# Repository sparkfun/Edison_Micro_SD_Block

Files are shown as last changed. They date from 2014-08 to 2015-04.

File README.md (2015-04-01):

SparkFun Edison microSD Block
============================

SparkFun Edison microSD Block

[*SparkFun Edison microSD Block(DEV-13041)*](https://www.sparkfun.com/products/13041)

The microSD Block equips your Edioson with mass storage capability, so you can use it for data-logging or other related projects.

Repository Contents
-------------------
* **/Hardware** - All Eagle Design files (.brd, .sch)
* **/Production** -Test bed files and production panel files

License Information
-------------------

The hardware is released under [Creative Commons ShareAlike 4.0 International](https://creativecommons.org/licenses/by-sa/4.0/).
The code is beerware; if you see me (or any other SparkFun employee) at the local, and you've found our code helpful, please buy us a round!

Distributed as-is; no warranty is given.

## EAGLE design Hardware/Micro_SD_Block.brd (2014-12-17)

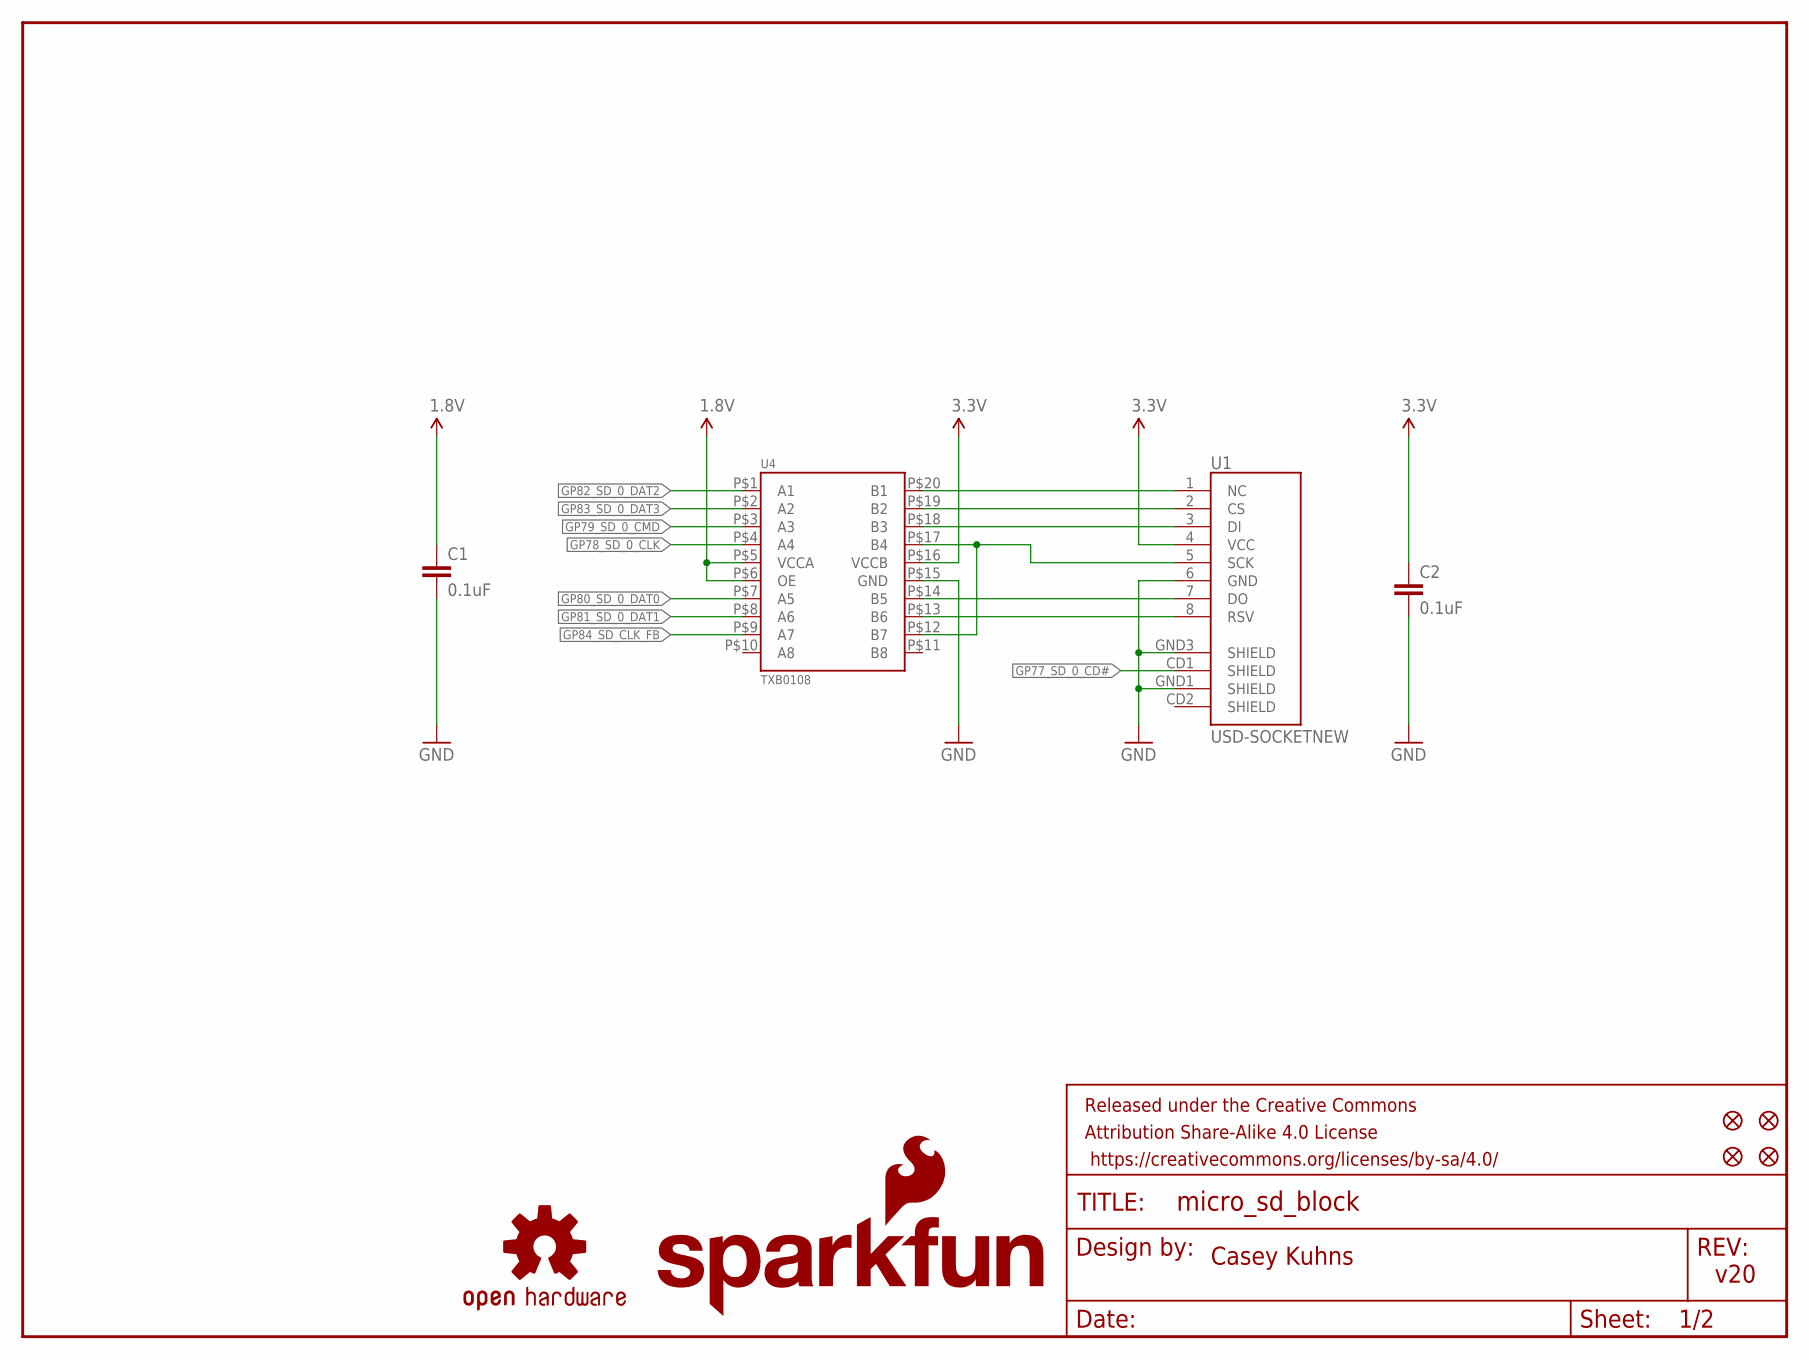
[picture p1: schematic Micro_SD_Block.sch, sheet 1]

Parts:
C1, C2: 0.1uF; 0603-CAP
FID1, FID2, FID3, FID4: FIDUCIAL1X2; FIDUCIAL-1X2
FRAME1: FRAME-LETTER; CREATIVE_COMMONS
LOGO1: OSHW-LOGOS; OSHW-LOGO-S
LOGO4: SFE_LOGO_NAME_FLAME.1_INCH; SFE_LOGO_NAME_FLAME_.1
U1: USD-SOCKETNEW; MICRO-SD-SOCKET-PP
U4: TXB0108; UFDFN-20

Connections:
1.8V: C1.1, U4.P$5 (VCCA), U4.P$6 (OE); also elsewhere on the board
3.3V: C2.1, U1.4 (VCC), U4.P$16 (VCCB); also elsewhere on the board
GND: C1.2, C2.2, U1.6 (GND), U1.GND1 (SHIELD), U1.GND3 (SHIELD), U4.P$15 (GND); also elsewhere on the board
GP77_SD_0_CD#: U1.CD1 (SHIELD); also elsewhere on the board
GP78_SD_0_CLK: U4.P$4 (A4); also elsewhere on the board
GP79_SD_0_CMD: U4.P$3 (A3); also elsewhere on the board
GP80_SD_0_DAT0: U4.P$7 (A5); also elsewhere on the board
GP81_SD_0_DAT1: U4.P$8 (A6); also elsewhere on the board
GP82_SD_0_DAT2: U4.P$1 (A1); also elsewhere on the board
GP83_SD_0_DAT3: U4.P$2 (A2); also elsewhere on the board
GP84_SD_CLK_FB: U4.P$9 (A7); also elsewhere on the board
unnamed: U1.1 (NC), U4.P$20 (B1)
unnamed: U1.2 (CS), U4.P$19 (B2)
unnamed: U1.3 (DI), U4.P$18 (B3)
unnamed: U1.7 (DO), U4.P$14 (B5)
unnamed: U1.8 (RSV), U4.P$13 (B6)
SCK: U1.5 (SCK), U4.P$12 (B7), U4.P$17 (B4)

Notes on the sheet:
Casey Kuhns
v20

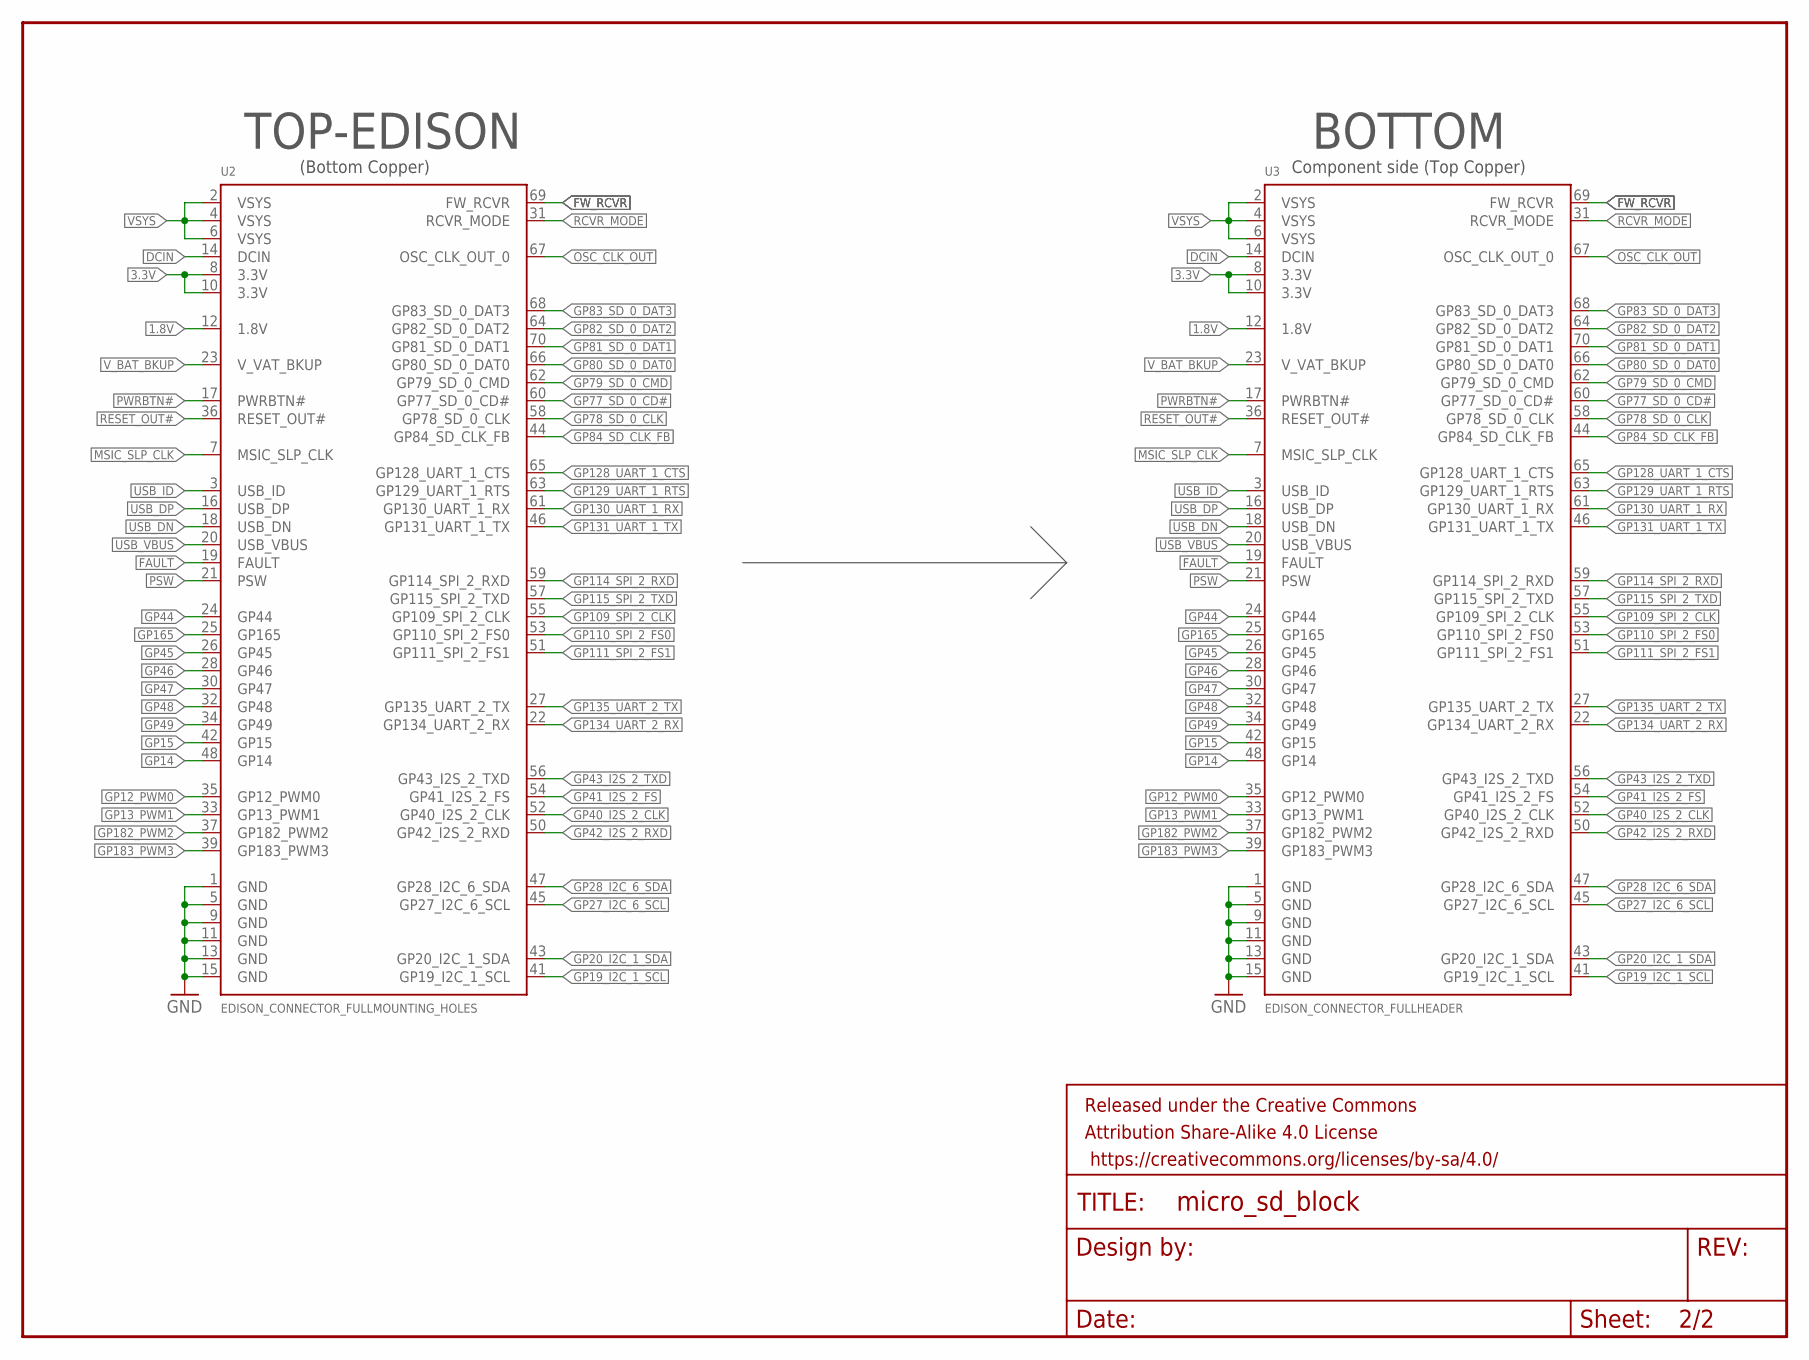
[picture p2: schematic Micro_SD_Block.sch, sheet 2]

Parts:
FRAME2: FRAME-LETTER; CREATIVE_COMMONS
U2: EDISON_CONNECTOR_FULLMOUNTING_HOLES; EDISON_DAUGHTER
U3: EDISON_CONNECTOR_FULLHEADER; DF40C-70DP-0.4(51)

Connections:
1.8V: U2.12 (1.8V), U3.12 (1.8V); also elsewhere on the board
3.3V: U2.8 (3.3V), U2.10 (3.3V), U3.8 (3.3V), U3.10 (3.3V); also elsewhere on the board
DCIN: U2.14 (DCIN), U3.14 (DCIN)
FAULT: U2.19 (FAULT), U3.19 (FAULT)
FW_RCVR: U2.69 (FW_RCVR), U3.69 (FW_RCVR)
GND: U2.1 (GND), U2.5 (GND), U2.9 (GND), U2.11 (GND), U2.13 (GND), U2.15 (GND), U3.1 (GND), U3.5 (GND), U3.9 (GND), U3.11 (GND), U3.13 (GND), U3.15 (GND); also elsewhere on the board
GP12_PWM0: U2.35 (GP12_PWM0), U3.35 (GP12_PWM0)
GP13_PWM1: U2.33 (GP13_PWM1), U3.33 (GP13_PWM1)
GP14: U2.48 (GP14), U3.48 (GP14)
GP15: U2.42 (GP15), U3.42 (GP15)
GP19_I2C_1_SCL: U2.41 (GP19_I2C_1_SCL), U3.41 (GP19_I2C_1_SCL)
GP20_I2C_1_SDA: U2.43 (GP20_I2C_1_SDA), U3.43 (GP20_I2C_1_SDA)
GP27_I2C_6_SCL: U2.45 (GP27_I2C_6_SCL), U3.45 (GP27_I2C_6_SCL)
GP28_I2C_6_SDA: U2.47 (GP28_I2C_6_SDA), U3.47 (GP28_I2C_6_SDA)
GP40_I2S_2_CLK: U2.52 (GP40_I2S_2_CLK), U3.52 (GP40_I2S_2_CLK)
GP41_I2S_2_FS: U2.54 (GP41_I2S_2_FS), U3.54 (GP41_I2S_2_FS)
GP42_I2S_2_RXD: U2.50 (GP42_I2S_2_RXD), U3.50 (GP42_I2S_2_RXD)
GP43_I2S_2_TXD: U2.56 (GP43_I2S_2_TXD), U3.56 (GP43_I2S_2_TXD)
GP44: U2.24 (GP44), U3.24 (GP44)
GP45: U2.26 (GP45), U3.26 (GP45)
GP46: U2.28 (GP46), U3.28 (GP46)
GP47: U2.30 (GP47), U3.30 (GP47)
GP48: U2.32 (GP48), U3.32 (GP48)
GP49: U2.34 (GP49), U3.34 (GP49)
GP77_SD_0_CD#: U2.60 (GP77_SD_0_CD#), U3.60 (GP77_SD_0_CD#); also elsewhere on the board
GP78_SD_0_CLK: U2.58 (GP78_SD_0_CLK), U3.58 (GP78_SD_0_CLK); also elsewhere on the board
GP79_SD_0_CMD: U2.62 (GP79_SD_0_CMD), U3.62 (GP79_SD_0_CMD); also elsewhere on the board
GP80_SD_0_DAT0: U2.66 (GP80_SD_0_DAT0), U3.66 (GP80_SD_0_DAT0); also elsewhere on the board
GP81_SD_0_DAT1: U2.70 (GP81_SD_0_DAT1), U3.70 (GP81_SD_0_DAT1); also elsewhere on the board
GP82_SD_0_DAT2: U2.64 (GP82_SD_0_DAT2), U3.64 (GP82_SD_0_DAT2); also elsewhere on the board
GP83_SD_0_DAT3: U2.68 (GP83_SD_0_DAT3), U3.68 (GP83_SD_0_DAT3); also elsewhere on the board
GP84_SD_CLK_FB: U2.44 (GP84_SD_CLK_FB), U3.44 (GP84_SD_CLK_FB); also elsewhere on the board
GP109_SPI_2_CLK: U2.55 (GP109_SPI_2_CLK), U3.55 (GP109_SPI_2_CLK)
GP110_SPI_2_FS0: U2.53 (GP110_SPI_2_FS0), U3.53 (GP110_SPI_2_FS0)
GP111_SPI_2_FS1: U2.51 (GP111_SPI_2_FS1), U3.51 (GP111_SPI_2_FS1)
GP114_SPI_2_RXD: U2.59 (GP114_SPI_2_RXD), U3.59 (GP114_SPI_2_RXD)
GP115_SPI_2_TXD: U2.57 (GP115_SPI_2_TXD), U3.57 (GP115_SPI_2_TXD)
GP128_UART_1_CTS: U2.65 (GP128_UART_1_CTS), U3.65 (GP128_UART_1_CTS)
GP129_UART_1_RTS: U2.63 (GP129_UART_1_RTS), U3.63 (GP129_UART_1_RTS)
GP130_UART_1_RX: U2.61 (GP130_UART_1_RX), U3.61 (GP130_UART_1_RX)
GP131_UART_1_TX: U2.46 (GP131_UART_1_TX), U3.46 (GP131_UART_1_TX)
GP134_UART_2_RX: U2.22 (GP134_UART_2_RX), U3.22 (GP134_UART_2_RX)
GP135_UART_2_TX: U2.27 (GP135_UART_2_TX), U3.27 (GP135_UART_2_TX)
GP165: U2.25 (GP165), U3.25 (GP165)
GP182_PWM2: U2.37 (GP182_PWM2), U3.37 (GP182_PWM2)
GP183_PWM3: U2.39 (GP183_PWM3), U3.39 (GP183_PWM3)
MSIC_SLP_CLK: U2.7 (MSIC_SLP_CLK), U3.7 (MSIC_SLP_CLK)
OSC_CLK_OUT: U2.67 (OSC_CLK_OUT_0), U3.67 (OSC_CLK_OUT_0)
PSW: U2.21 (PSW), U3.21 (PSW)
PWRBTN#: U2.17 (PWRBTN#), U3.17 (PWRBTN#)
RCVR_MODE: U2.31 (RCVR_MODE), U3.31 (RCVR_MODE)
RESET_OUT#: U2.36 (RESET_OUT#), U3.36 (RESET_OUT#)
USB_DN: U2.18 (USB_DN), U3.18 (USB_DN)
USB_DP: U2.16 (USB_DP), U3.16 (USB_DP)
USB_ID: U2.3 (USB_ID), U3.3 (USB_ID)
USB_VBUS: U2.20 (USB_VBUS), U3.20 (USB_VBUS)
VSYS: U2.2 (VSYS), U2.4 (VSYS), U2.6 (VSYS), U3.2 (VSYS), U3.4 (VSYS), U3.6 (VSYS)
V_BAT_BKUP: U2.23 (V_VAT_BKUP), U3.23 (V_VAT_BKUP)

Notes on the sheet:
TOP-EDISON
BOTTOM
Component side (Top Copper)
(Bottom Copper)

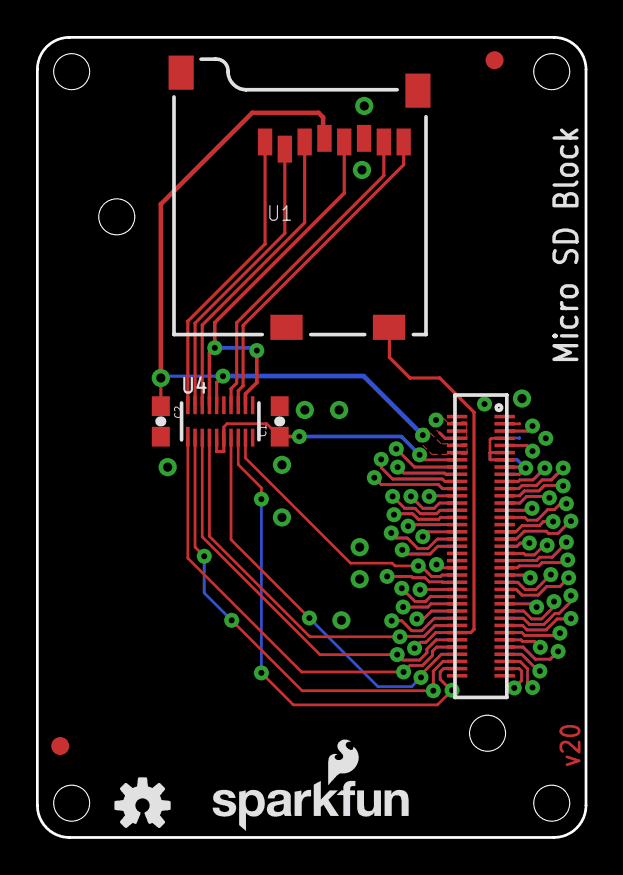
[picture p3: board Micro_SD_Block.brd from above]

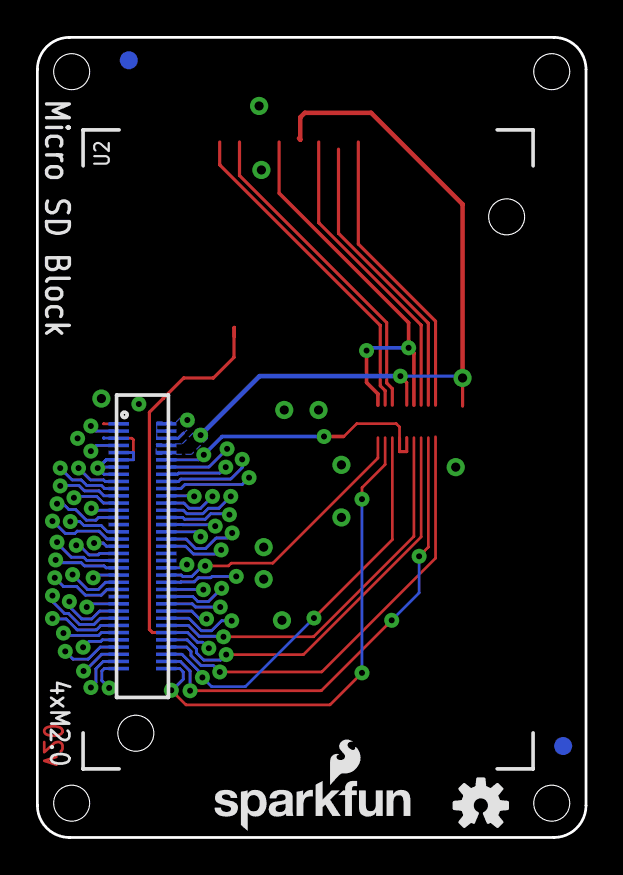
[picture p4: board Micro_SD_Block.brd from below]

Board: 2 copper layers, 30.5 x 44.5 mm, 16 parts (6 on the bottom side), 64 nets.

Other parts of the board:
LOGO2: OSHW-LOGOS; OSHW-LOGO-S
LOGO3: SFE_LOGO_NAME_FLAME.1_INCH; SFE_LOGO_NAME_FLAME_.1

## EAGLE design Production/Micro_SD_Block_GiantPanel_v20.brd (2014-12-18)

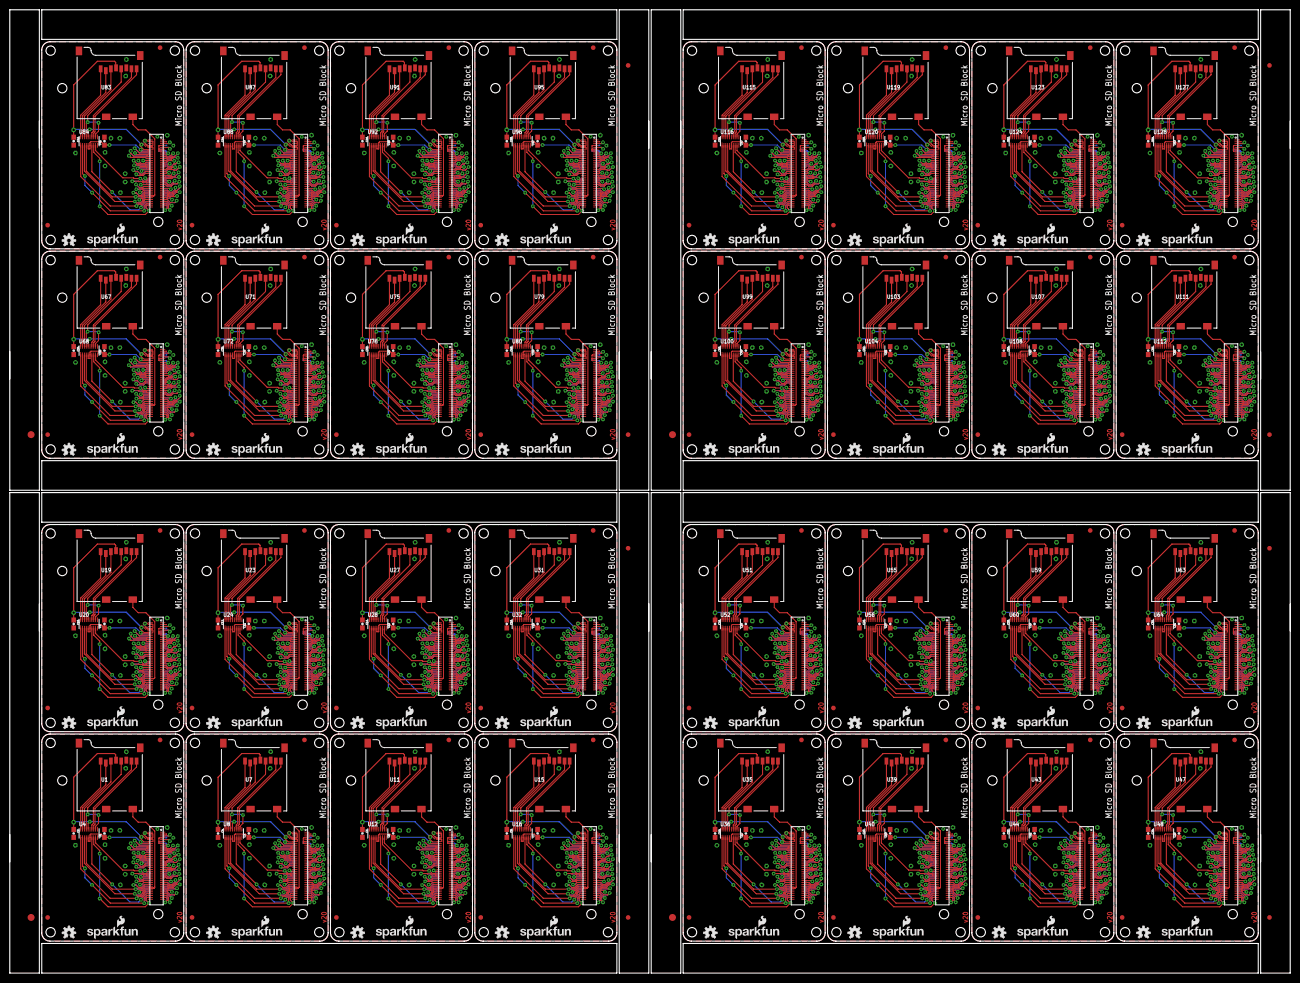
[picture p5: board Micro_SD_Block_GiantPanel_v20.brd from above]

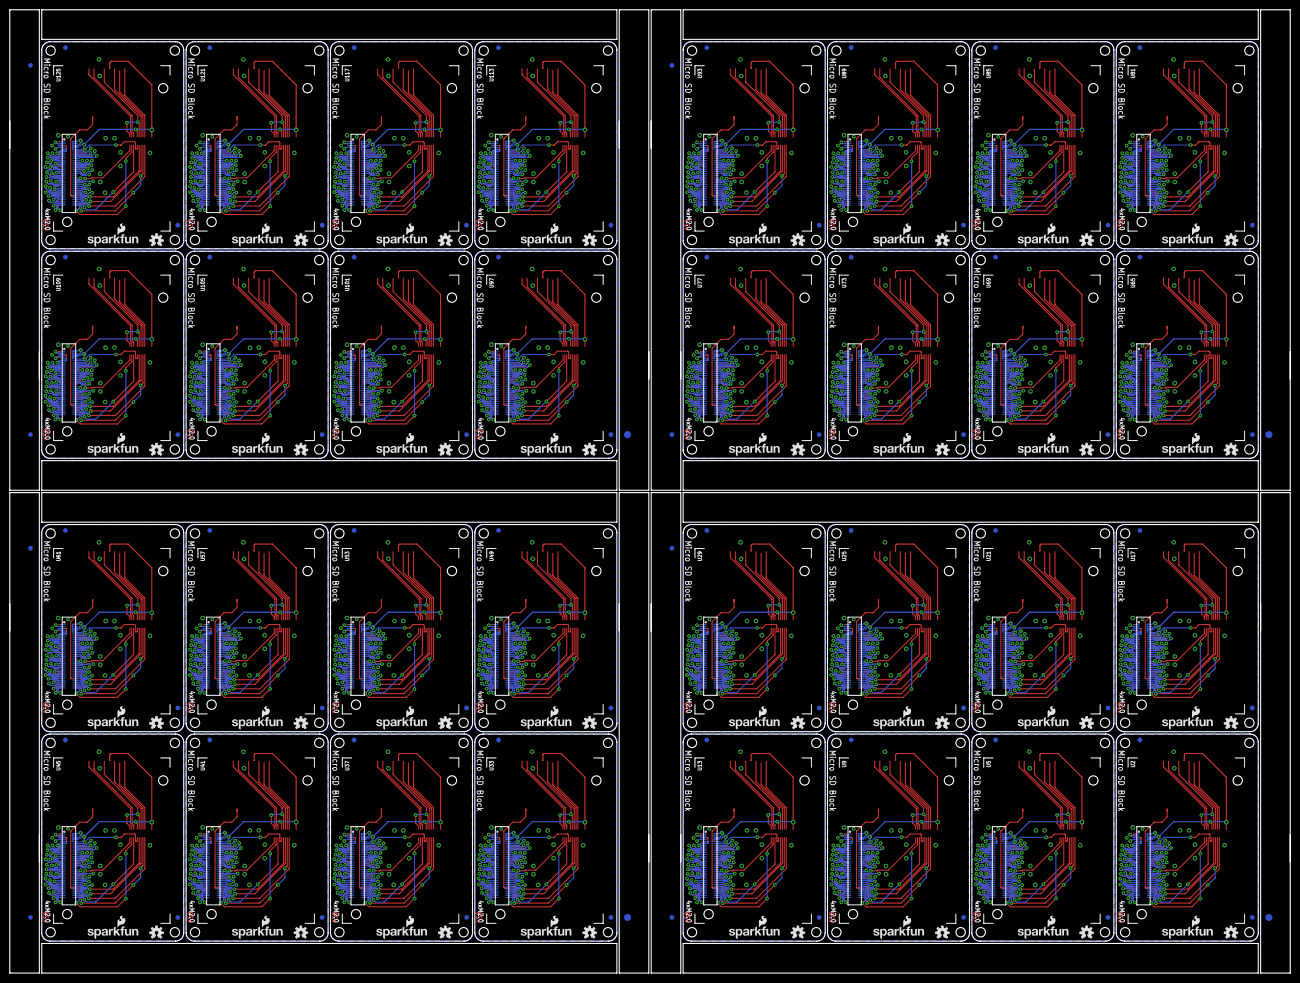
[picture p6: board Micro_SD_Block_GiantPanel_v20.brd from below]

Board: 2 copper layers, 274.8 x 206.8 mm, 472 parts (204 on the bottom side), 2048 nets.

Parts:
C1, C2, C3, C4, C5, C6, C7, C8, C9, C10, C11, C12, C13, C14, C15, C16, C17, C18, C19, C20, C21, C22, C23, C24, C25, C26, C27, C28, C29, C30, C31, C32, C33, C34, C35, C36, C37, C38, C39, C40, C41, C42, C43, C44, C45, C46, C47, C48, C49, C50, C51, C52, C53, C54, C55, C56, C57, C58, C59, C60, C61, C62, C63, C64: 0.1uF; 0603-CAP
E$1, E$2, E$9, E$10, E$15, E$16, E$21, E$22: FIDUCIAL-1.5X3
E$3, E$4, E$5, E$6, E$7, E$8, E$11, E$12, E$13, E$14, E$17, E$18, E$19, E$20, E$23, E$24: FIDUCIAL-1X2
FID1, FID2, FID3, FID4, FID5, FID6, FID7, FID8, FID9, FID10, FID11, FID12, FID13, FID14, FID15, FID16, FID17, FID18, FID19, FID20, FID21, FID22, FID23, FID24, FID25, FID26, FID27, FID28, FID29, FID30, FID31, FID32, FID33, FID34, FID35, FID36, FID37, FID38, FID39, FID40, FID41, FID42, FID43, FID44, FID45, FID46, FID47, FID48, FID49, FID50, FID51, FID52, FID53, FID54, FID55, FID56, FID57, FID58, FID59, FID60, FID61, FID62, FID63, FID64, FID65, FID66, FID67, FID68, FID69, FID70, FID71, FID72, FID73, FID74, FID75, FID76, FID77, FID78, FID79, FID80, FID81, FID82, FID83, FID84, FID85, FID86, FID87, FID88, FID89, FID90, FID91, FID92, FID93, FID94, FID95, FID96, FID97, FID98, FID99, FID100, FID101, FID102, FID103, FID104, FID105, FID106, FID107, FID108, FID109, FID110, FID111, FID112, FID113, FID114, FID115, FID116, FID117, FID118, FID119, FID120, FID121, FID122, FID123, FID124, FID125, FID126, FID127, FID128: FIDUCIAL1X2; FIDUCIAL-1X2
LOGO1, LOGO2, LOGO5, LOGO7, LOGO9, LOGO11, LOGO13, LOGO15, LOGO17, LOGO19, LOGO21, LOGO23, LOGO25, LOGO27, LOGO29, LOGO31, LOGO33, LOGO35, LOGO37, LOGO39, LOGO41, LOGO43, LOGO45, LOGO47, LOGO49, LOGO51, LOGO53, LOGO55, LOGO57, LOGO59, LOGO61, LOGO63, LOGO65, LOGO67, LOGO69, LOGO71, LOGO73, LOGO75, LOGO77, LOGO79, LOGO81, LOGO83, LOGO85, LOGO87, LOGO89, LOGO91, LOGO93, LOGO95, LOGO97, LOGO99, LOGO101, LOGO103, LOGO105, LOGO107, LOGO109, LOGO111, LOGO113, LOGO115, LOGO117, LOGO119, LOGO121, LOGO123, LOGO125, LOGO127: OSHW-LOGOS; OSHW-LOGO-S
LOGO3, LOGO4, LOGO6, LOGO8, LOGO10, LOGO12, LOGO14, LOGO16, LOGO18, LOGO20, LOGO22, LOGO24, LOGO26, LOGO28, LOGO30, LOGO32, LOGO34, LOGO36, LOGO38, LOGO40, LOGO42, LOGO44, LOGO46, LOGO48, LOGO50, LOGO52, LOGO54, LOGO56, LOGO58, LOGO60, LOGO62, LOGO64, LOGO66, LOGO68, LOGO70, LOGO72, LOGO74, LOGO76, LOGO78, LOGO80, LOGO82, LOGO84, LOGO86, LOGO88, LOGO90, LOGO92, LOGO94, LOGO96, LOGO98, LOGO100, LOGO102, LOGO104, LOGO106, LOGO108, LOGO110, LOGO112, LOGO114, LOGO116, LOGO118, LOGO120, LOGO122, LOGO124, LOGO126, LOGO128: SFE_LOGO_NAME_FLAME.1_INCH; SFE_LOGO_NAME_FLAME_.1
U1, U7, U11, U15, U19, U23, U27, U31, U35, U39, U43, U47, U51, U55, U59, U63, U67, U71, U75, U79, U83, U87, U91, U95, U99, U103, U107, U111, U115, U119, U123, U127: USD-SOCKETNEW; MICRO-SD-SOCKET-PP
U2, U5, U9, U13, U17, U21, U25, U29, U33, U37, U41, U45, U49, U53, U57, U61, U65, U69, U73, U77, U81, U85, U89, U93, U97, U101, U105, U109, U113, U117, U121, U125: EDISON_CONNECTOR_FULLMOUNTING_HOLES; EDISON_DAUGHTER
U3, U6, U10, U14, U18, U22, U26, U30, U34, U38, U42, U46, U50, U54, U58, U62, U66, U70, U74, U78, U82, U86, U90, U94, U98, U102, U106, U110, U114, U118, U122, U126: EDISON_CONNECTOR_FULLHEADER; DF40C-70DP-0.4(51)
U4, U8, U12, U16, U20, U24, U28, U32, U36, U40, U44, U48, U52, U56, U60, U64, U68, U72, U76, U80, U84, U88, U92, U96, U100, U104, U108, U112, U116, U120, U124, U128: TXB0108; UFDFN-20

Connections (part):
1.8V: C1.1, U2.12, U3.12, U4.P$5, U4.P$6
1.8V1: C3.1, U5.12, U6.12, U8.P$5, U8.P$6
1.8V2: C5.1, U9.12, U10.12, U12.P$5, U12.P$6
1.8V3: C7.1, U13.12, U14.12, U16.P$5, U16.P$6
1.8V4: C9.1, U17.12, U18.12, U20.P$5, U20.P$6
1.8V5: C11.1, U21.12, U22.12, U24.P$5, U24.P$6
1.8V6: C13.1, U25.12, U26.12, U28.P$5, U28.P$6
1.8V7: C15.1, U29.12, U30.12, U32.P$5, U32.P$6
1.8V8: C17.1, U33.12, U34.12, U36.P$5, U36.P$6
1.8V9: C19.1, U37.12, U38.12, U40.P$5, U40.P$6
1.8V10: C21.1, U41.12, U42.12, U44.P$5, U44.P$6
1.8V11: C23.1, U45.12, U46.12, U48.P$5, U48.P$6
1.8V12: C25.1, U49.12, U50.12, U52.P$5, U52.P$6
1.8V13: C27.1, U53.12, U54.12, U56.P$5, U56.P$6
1.8V14: C29.1, U57.12, U58.12, U60.P$5, U60.P$6
1.8V15: C31.1, U61.12, U62.12, U64.P$5, U64.P$6
1.8V16: C33.1, U65.12, U66.12, U68.P$5, U68.P$6
1.8V17: C35.1, U69.12, U70.12, U72.P$5, U72.P$6
1.8V18: C37.1, U73.12, U74.12, U76.P$5, U76.P$6
1.8V19: C39.1, U77.12, U78.12, U80.P$5, U80.P$6
1.8V20: C41.1, U81.12, U82.12, U84.P$5, U84.P$6
1.8V21: C43.1, U85.12, U86.12, U88.P$5, U88.P$6
1.8V22: C45.1, U89.12, U90.12, U92.P$5, U92.P$6
1.8V23: C47.1, U93.12, U94.12, U96.P$5, U96.P$6
1.8V24: C49.1, U97.12, U98.12, U100.P$5, U100.P$6
1.8V25: C51.1, U101.12, U102.12, U104.P$5, U104.P$6
1.8V26: C53.1, U105.12, U106.12, U108.P$5, U108.P$6
1.8V27: C55.1, U109.12, U110.12, U112.P$5, U112.P$6
1.8V28: C57.1, U113.12, U114.12, U116.P$5, U116.P$6
1.8V29: C59.1, U117.12, U118.12, U120.P$5, U120.P$6
1.8V30: C61.1, U121.12, U122.12, U124.P$5, U124.P$6
1.8V31: C63.1, U125.12, U126.12, U128.P$5, U128.P$6
3.3V: C2.1, U1.4, U2.8, U2.10, U3.8, U3.10, U4.P$16
3.3V1: C4.1, U5.8, U5.10, U6.8, U6.10, U7.4, U8.P$16
3.3V2: C6.1, U9.8, U9.10, U10.8, U10.10, U11.4, U12.P$16
3.3V3: C8.1, U13.8, U13.10, U14.8, U14.10, U15.4, U16.P$16
3.3V4: C10.1, U17.8, U17.10, U18.8, U18.10, U19.4, U20.P$16
3.3V5: C12.1, U21.8, U21.10, U22.8, U22.10, U23.4, U24.P$16
3.3V6: C14.1, U25.8, U25.10, U26.8, U26.10, U27.4, U28.P$16
3.3V7: C16.1, U29.8, U29.10, U30.8, U30.10, U31.4, U32.P$16
3.3V8: C18.1, U33.8, U33.10, U34.8, U34.10, U35.4, U36.P$16
3.3V9: C20.1, U37.8, U37.10, U38.8, U38.10, U39.4, U40.P$16
3.3V10: C22.1, U41.8, U41.10, U42.8, U42.10, U43.4, U44.P$16
3.3V11: C24.1, U45.8, U45.10, U46.8, U46.10, U47.4, U48.P$16
3.3V12: C26.1, U49.8, U49.10, U50.8, U50.10, U51.4, U52.P$16
3.3V13: C28.1, U53.8, U53.10, U54.8, U54.10, U55.4, U56.P$16
3.3V14: C30.1, U57.8, U57.10, U58.8, U58.10, U59.4, U60.P$16
3.3V15: C32.1, U61.8, U61.10, U62.8, U62.10, U63.4, U64.P$16
3.3V16: C34.1, U65.8, U65.10, U66.8, U66.10, U67.4, U68.P$16
3.3V17: C36.1, U69.8, U69.10, U70.8, U70.10, U71.4, U72.P$16
3.3V18: C38.1, U73.8, U73.10, U74.8, U74.10, U75.4, U76.P$16
3.3V19: C40.1, U77.8, U77.10, U78.8, U78.10, U79.4, U80.P$16
3.3V20: C42.1, U81.8, U81.10, U82.8, U82.10, U83.4, U84.P$16
3.3V21: C44.1, U85.8, U85.10, U86.8, U86.10, U87.4, U88.P$16
3.3V22: C46.1, U89.8, U89.10, U90.8, U90.10, U91.4, U92.P$16
3.3V23: C48.1, U93.8, U93.10, U94.8, U94.10, U95.4, U96.P$16
3.3V24: C50.1, U97.8, U97.10, U98.8, U98.10, U99.4, U100.P$16
3.3V25: C52.1, U101.8, U101.10, U102.8, U102.10, U103.4, U104.P$16
3.3V26: C54.1, U105.8, U105.10, U106.8, U106.10, U107.4, U108.P$16
3.3V27: C56.1, U109.8, U109.10, U110.8, U110.10, U111.4, U112.P$16
3.3V28: C58.1, U113.8, U113.10, U114.8, U114.10, U115.4, U116.P$16
3.3V29: C60.1, U117.8, U117.10, U118.8, U118.10, U119.4, U120.P$16
3.3V30: C62.1, U121.8, U121.10, U122.8, U122.10, U123.4, U124.P$16
3.3V31: C64.1, U125.8, U125.10, U126.8, U126.10, U127.4, U128.P$16
DCIN: U2.14, U3.14
DCIN1: U5.14, U6.14
DCIN2: U9.14, U10.14
DCIN3: U13.14, U14.14
DCIN4: U17.14, U18.14
DCIN5: U21.14, U22.14
DCIN6: U25.14, U26.14
DCIN7: U29.14, U30.14
DCIN8: U33.14, U34.14
DCIN9: U37.14, U38.14
DCIN10: U41.14, U42.14
DCIN11: U45.14, U46.14
DCIN12: U49.14, U50.14
DCIN13: U53.14, U54.14
DCIN14: U57.14, U58.14
DCIN15: U61.14, U62.14
DCIN16: U65.14, U66.14
DCIN17: U69.14, U70.14
DCIN18: U73.14, U74.14
DCIN19: U77.14, U78.14
DCIN20: U81.14, U82.14
DCIN21: U85.14, U86.14
DCIN22: U89.14, U90.14
DCIN23: U93.14, U94.14
DCIN24: U97.14, U98.14
DCIN25: U101.14, U102.14
DCIN26: U105.14, U106.14
DCIN27: U109.14, U110.14
DCIN28: U113.14, U114.14
DCIN29: U117.14, U118.14
DCIN30: U121.14, U122.14
DCIN31: U125.14, U126.14
FAULT: U2.19, U3.19
FAULT1: U5.19, U6.19
FAULT2: U9.19, U10.19
FAULT3: U13.19, U14.19
FAULT4: U17.19, U18.19
FAULT5: U21.19, U22.19
FAULT6: U25.19, U26.19
FAULT7: U29.19, U30.19
FAULT8: U33.19, U34.19
FAULT9: U37.19, U38.19
FAULT10: U41.19, U42.19
FAULT11: U45.19, U46.19
FAULT12: U49.19, U50.19
FAULT13: U53.19, U54.19
FAULT14: U57.19, U58.19
FAULT15: U61.19, U62.19
FAULT16: U65.19, U66.19
FAULT17: U69.19, U70.19
FAULT18: U73.19, U74.19
FAULT19: U77.19, U78.19
FAULT20: U81.19, U82.19
FAULT21: U85.19, U86.19
FAULT22: U89.19, U90.19
FAULT23: U93.19, U94.19
FAULT24: U97.19, U98.19
FAULT25: U101.19, U102.19
FAULT26: U105.19, U106.19
FAULT27: U109.19, U110.19
FAULT28: U113.19, U114.19
FAULT29: U117.19, U118.19
FAULT30: U121.19, U122.19
FAULT31: U125.19, U126.19
FW_RCVR: U2.69, U3.69
FW_RCVR1: U5.69, U6.69
FW_RCVR2: U9.69, U10.69
FW_RCVR3: U13.69, U14.69
FW_RCVR4: U17.69, U18.69
FW_RCVR5: U21.69, U22.69
FW_RCVR6: U25.69, U26.69
FW_RCVR7: U29.69, U30.69
FW_RCVR8: U33.69, U34.69
FW_RCVR9: U37.69, U38.69
FW_RCVR10: U41.69, U42.69
FW_RCVR11: U45.69, U46.69
FW_RCVR12: U49.69, U50.69
FW_RCVR13: U53.69, U54.69
FW_RCVR14: U57.69, U58.69
FW_RCVR15: U61.69, U62.69
FW_RCVR16: U65.69, U66.69
FW_RCVR17: U69.69, U70.69
FW_RCVR18: U73.69, U74.69
FW_RCVR19: U77.69, U78.69
FW_RCVR20: U81.69, U82.69
FW_RCVR21: U85.69, U86.69
FW_RCVR22: U89.69, U90.69
FW_RCVR23: U93.69, U94.69
FW_RCVR24: U97.69, U98.69
FW_RCVR25: U101.69, U102.69
FW_RCVR26: U105.69, U106.69
FW_RCVR27: U109.69, U110.69
FW_RCVR28: U113.69, U114.69
FW_RCVR29: U117.69, U118.69
FW_RCVR30: U121.69, U122.69
FW_RCVR31: U125.69, U126.69
GND: C1.2, C2.2, U1.6, U1.GND1, U1.GND3, U2.1, U2.5, U2.9, U2.11, U2.13, U2.15, U3.1, U3.5, U3.9, U3.11, U3.13, U3.15, U4.P$15
GND1: C3.2, C4.2, U5.1, U5.5, U5.9, U5.11, U5.13, U5.15, U6.1, U6.5, U6.9, U6.11, U6.13, U6.15, U7.6, U7.GND1, U7.GND3, U8.P$15
GND2: C5.2, C6.2, U9.1, U9.5, U9.9, U9.11, U9.13, U9.15, U10.1, U10.5, U10.9, U10.11, U10.13, U10.15, U11.6, U11.GND1, U11.GND3, U12.P$15
GND3: C7.2, C8.2, U13.1, U13.5, U13.9, U13.11, U13.13, U13.15, U14.1, U14.5, U14.9, U14.11, U14.13, U14.15, U15.6, U15.GND1, U15.GND3, U16.P$15
GND4: C9.2, C10.2, U17.1, U17.5, U17.9, U17.11, U17.13, U17.15, U18.1, U18.5, U18.9, U18.11, U18.13, U18.15, U19.6, U19.GND1, U19.GND3, U20.P$15
GND5: C11.2, C12.2, U21.1, U21.5, U21.9, U21.11, U21.13, U21.15, U22.1, U22.5, U22.9, U22.11, U22.13, U22.15, U23.6, U23.GND1, U23.GND3, U24.P$15
GND6: C13.2, C14.2, U25.1, U25.5, U25.9, U25.11, U25.13, U25.15, U26.1, U26.5, U26.9, U26.11, U26.13, U26.15, U27.6, U27.GND1, U27.GND3, U28.P$15
GND7: C15.2, C16.2, U29.1, U29.5, U29.9, U29.11, U29.13, U29.15, U30.1, U30.5, U30.9, U30.11, U30.13, U30.15, U31.6, U31.GND1, U31.GND3, U32.P$15
GND8: C17.2, C18.2, U33.1, U33.5, U33.9, U33.11, U33.13, U33.15, U34.1, U34.5, U34.9, U34.11, U34.13, U34.15, U35.6, U35.GND1, U35.GND3, U36.P$15
GND9: C19.2, C20.2, U37.1, U37.5, U37.9, U37.11, U37.13, U37.15, U38.1, U38.5, U38.9, U38.11, U38.13, U38.15, U39.6, U39.GND1, U39.GND3, U40.P$15
GND10: C21.2, C22.2, U41.1, U41.5, U41.9, U41.11, U41.13, U41.15, U42.1, U42.5, U42.9, U42.11, U42.13, U42.15, U43.6, U43.GND1, U43.GND3, U44.P$15
GND11: C23.2, C24.2, U45.1, U45.5, U45.9, U45.11, U45.13, U45.15, U46.1, U46.5, U46.9, U46.11, U46.13, U46.15, U47.6, U47.GND1, U47.GND3, U48.P$15
GND12: C25.2, C26.2, U49.1, U49.5, U49.9, U49.11, U49.13, U49.15, U50.1, U50.5, U50.9, U50.11, U50.13, U50.15, U51.6, U51.GND1, U51.GND3, U52.P$15
GND13: C27.2, C28.2, U53.1, U53.5, U53.9, U53.11, U53.13, U53.15, U54.1, U54.5, U54.9, U54.11, U54.13, U54.15, U55.6, U55.GND1, U55.GND3, U56.P$15
GND14: C29.2, C30.2, U57.1, U57.5, U57.9, U57.11, U57.13, U57.15, U58.1, U58.5, U58.9, U58.11, U58.13, U58.15, U59.6, U59.GND1, U59.GND3, U60.P$15
GND15: C31.2, C32.2, U61.1, U61.5, U61.9, U61.11, U61.13, U61.15, U62.1, U62.5, U62.9, U62.11, U62.13, U62.15, U63.6, U63.GND1, U63.GND3, U64.P$15
GND16: C33.2, C34.2, U65.1, U65.5, U65.9, U65.11, U65.13, U65.15, U66.1, U66.5, U66.9, U66.11, U66.13, U66.15, U67.6, U67.GND1, U67.GND3, U68.P$15
GND17: C35.2, C36.2, U69.1, U69.5, U69.9, U69.11, U69.13, U69.15, U70.1, U70.5, U70.9, U70.11, U70.13, U70.15, U71.6, U71.GND1, U71.GND3, U72.P$15
GND18: C37.2, C38.2, U73.1, U73.5, U73.9, U73.11, U73.13, U73.15, U74.1, U74.5, U74.9, U74.11, U74.13, U74.15, U75.6, U75.GND1, U75.GND3, U76.P$15
GND19: C39.2, C40.2, U77.1, U77.5, U77.9, U77.11, U77.13, U77.15, U78.1, U78.5, U78.9, U78.11, U78.13, U78.15, U79.6, U79.GND1, U79.GND3, U80.P$15
GND20: C41.2, C42.2, U81.1, U81.5, U81.9, U81.11, U81.13, U81.15, U82.1, U82.5, U82.9, U82.11, U82.13, U82.15, U83.6, U83.GND1, U83.GND3, U84.P$15
GND21: C43.2, C44.2, U85.1, U85.5, U85.9, U85.11, U85.13, U85.15, U86.1, U86.5, U86.9, U86.11, U86.13, U86.15, U87.6, U87.GND1, U87.GND3, U88.P$15
GND22: C45.2, C46.2, U89.1, U89.5, U89.9, U89.11, U89.13, U89.15, U90.1, U90.5, U90.9, U90.11, U90.13, U90.15, U91.6, U91.GND1, U91.GND3, U92.P$15
GND23: C47.2, C48.2, U93.1, U93.5, U93.9, U93.11, U93.13, U93.15, U94.1, U94.5, U94.9, U94.11, U94.13, U94.15, U95.6, U95.GND1, U95.GND3, U96.P$15
GND24: C49.2, C50.2, U97.1, U97.5, U97.9, U97.11, U97.13, U97.15, U98.1, U98.5, U98.9, U98.11, U98.13, U98.15, U99.6, U99.GND1, U99.GND3, U100.P$15
GND25: C51.2, C52.2, U101.1, U101.5, U101.9, U101.11, U101.13, U101.15, U102.1, U102.5, U102.9, U102.11, U102.13, U102.15, U103.6, U103.GND1, U103.GND3, U104.P$15
GND26: C53.2, C54.2, U105.1, U105.5, U105.9, U105.11, U105.13, U105.15, U106.1, U106.5, U106.9, U106.11, U106.13, U106.15, U107.6, U107.GND1, U107.GND3, U108.P$15
GND27: C55.2, C56.2, U109.1, U109.5, U109.9, U109.11, U109.13, U109.15, U110.1, U110.5, U110.9, U110.11, U110.13, U110.15, U111.6, U111.GND1, U111.GND3, U112.P$15
GND28: C57.2, C58.2, U113.1, U113.5, U113.9, U113.11, U113.13, U113.15, U114.1, U114.5, U114.9, U114.11, U114.13, U114.15, U115.6, U115.GND1, U115.GND3, U116.P$15
GND29: C59.2, C60.2, U117.1, U117.5, U117.9, U117.11, U117.13, U117.15, U118.1, U118.5, U118.9, U118.11, U118.13, U118.15, U119.6, U119.GND1, U119.GND3, U120.P$15
GND30: C61.2, C62.2, U121.1, U121.5, U121.9, U121.11, U121.13, U121.15, U122.1, U122.5, U122.9, U122.11, U122.13, U122.15, U123.6, U123.GND1, U123.GND3, U124.P$15
GND31: C63.2, C64.2, U125.1, U125.5, U125.9, U125.11, U125.13, U125.15, U126.1, U126.5, U126.9, U126.11, U126.13, U126.15, U127.6, U127.GND1, U127.GND3, U128.P$15
GP1: U5.48, U6.48
GP2: U5.42, U6.42
GP3: U5.34, U6.34
GP4: U5.32, U6.32
GP5: U5.30, U6.30
GP6: U5.28, U6.28
GP7: U5.26, U6.26
GP8: U5.25, U6.25
GP9: U5.24, U6.24
GP10: U9.48, U10.48
GP11: U9.42, U10.42
GP12: U9.34, U10.34
GP12_PWM0: U2.35, U3.35
GP12_PWM1: U5.35, U6.35
GP12_PWM2: U9.35, U10.35
GP12_PWM3: U13.35, U14.35
GP12_PWM4: U17.35, U18.35
GP12_PWM5: U21.35, U22.35
GP12_PWM6: U25.35, U26.35
GP12_PWM7: U29.35, U30.35
GP12_PWM8: U33.35, U34.35
GP12_PWM9: U37.35, U38.35
GP12_PWM10: U41.35, U42.35
GP12_PWM11: U45.35, U46.35
GP12_PWM12: U49.35, U50.35
GP12_PWM13: U53.35, U54.35
GP12_PWM14: U57.35, U58.35
GP12_PWM15: U61.35, U62.35
GP12_PWM16: U65.35, U66.35
GP12_PWM17: U69.35, U70.35
GP12_PWM18: U73.35, U74.35
GP12_PWM19: U77.35, U78.35
GP12_PWM20: U81.35, U82.35
GP12_PWM21: U85.35, U86.35
GP12_PWM22: U89.35, U90.35
GP12_PWM23: U93.35, U94.35
GP12_PWM24: U97.35, U98.35
GP12_PWM25: U101.35, U102.35
GP12_PWM26: U105.35, U106.35
GP12_PWM27: U109.35, U110.35
GP12_PWM28: U113.35, U114.35
GP12_PWM29: U117.35, U118.35
GP12_PWM30: U121.35, U122.35
GP12_PWM31: U125.35, U126.35
GP13: U9.32, U10.32
GP13_PWM1: U2.33, U3.33
GP13_PWM2: U5.33, U6.33
GP13_PWM3: U9.33, U10.33
GP13_PWM4: U13.33, U14.33
GP13_PWM5: U17.33, U18.33
GP13_PWM6: U21.33, U22.33
GP13_PWM7: U25.33, U26.33
GP13_PWM8: U29.33, U30.33
GP13_PWM9: U33.33, U34.33
GP13_PWM10: U37.33, U38.33
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

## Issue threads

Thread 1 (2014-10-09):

Silk on jumpers

lewispg228, 2014-10-09:
Do you maybe want to add some silk to the jumpers on the board so we know what they do? Also, the text object in the schematic could be a little more descriptive...

ToniCorinne, 2015-04-01:
Closing out as no longer an issue.

Closed 2015-04-01.

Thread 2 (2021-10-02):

Card Detect polarity is wrong

andy-shev, 2021-10-02:
It appears that software used to work by luck with the Card Detection on this board. Intel PCB is using Active Low, while your design seems using Active High. More details are here: https://github.com/edison-fw/meta-intel-edison/issues/135

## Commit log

2014-08-09 initial commit with templates
    [Mezzanine_Template.brd, Mezzanine_Template.sch]
2014-08-09 renamed template and added SD, still needs work for level shifting
    [Mezzanine_SD_Card.brd, Mezzanine_SD_Card.sch]
2014-08-09 added fiducials
    [Mezzanine_SD_Card.brd, Mezzanine_SD_Card.sch]
2014-08-11 Layout complete, Ready for review.
    [Mezzanine_SD_Card.brd, Mezzanine_SD_Card.sch]
2014-08-11 added version numbers
    [Mezzanine_SD_Card.sch]
2014-08-12 removed Edzzanine from name
    [Mezzanine_SD_Card.brd]
2014-08-14 fixed OE to high
    [Mezzanine_SD_Card.brd, Mezzanine_SD_Card.sch]
2014-09-23 work in progress
    [Mezzanine_SD_Card.brd, Mezzanine_SD_Card.sch]
2014-09-25 Added DCIN pin cleaned up dimensions cleaned up names on board created clock feedback test circuit
    [Mezzanine_SD_Card.brd, Mezzanine_SD_Card.sch]
2014-09-25 renamed files
    [Micro_SD_Block.brd, Micro_SD_Block.sch]
2014-10-16 removed thermals on connectors updated connector to new foot print updated version number corrected silk positions
    [Micro_SD_Block.brd, Micro_SD_Block.sch]
2014-10-17 modified traces to eliminate bridging. Selected FB circuit to use in production.
    [Micro_SD_Block.brd, Micro_SD_Block.sch]
2014-10-17 Moved 3.3v bus out from under highspeed lines updated edison connector footprint to remove jumpers removed jumpers from txb0108
    TODO: Remove P$#'s from txb0108 in library
    [Micro_SD_Block.brd, Micro_SD_Block.sch]
2014-10-17 Ready for reds Struck one weird leftover via Renamed TXB0108 chip refdes To-do: fix the TXB0108 symbol to remove P$ from pin names. Do in library and update to design!
    [Micro_SD_Block.brd, Micro_SD_Block.sch]
2014-10-22 created v10 panels
    [Micro_SD_Block-GiantPanel-v10.brd, Micro_SD_Block-Panel-v10.brd]
2014-12-17 fixed CD grounding issue, CD1 and CD2 are connected internally.
    [Micro_SD_Block.brd, Micro_SD_Block.sch]
2014-12-18 removed v10 panels and created v20 panels
    [Micro_SD_Block_GiantPanel_v20.brd, Micro_SD_Block_Panel_v20.brd]
2015-04-01 Updating README, directory name
    [Micro_SD_Block_GiantPanel_v20.brd, Micro_SD_Block_Panel_v20.brd]

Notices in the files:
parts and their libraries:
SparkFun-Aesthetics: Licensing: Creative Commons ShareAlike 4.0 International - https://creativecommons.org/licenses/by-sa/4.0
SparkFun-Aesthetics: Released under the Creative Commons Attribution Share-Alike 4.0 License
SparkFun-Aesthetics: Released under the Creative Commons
